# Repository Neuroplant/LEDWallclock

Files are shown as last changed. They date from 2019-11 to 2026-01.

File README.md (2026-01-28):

# LEDWallclock
very low cost Wallclock based on ESP01 and WS2812B Leds 

  # Features:
  - get current time from NTP (instead of buying a RTC-Modul)
  - use free pixels as Color light (MQTT /Clock/colorRGB/set)
  - use Alarm-time (MQTT /Clock/alarm/set)
  - Animation-Alarm (MQTT /Clock/effect/set)

  # MQTT
  you will need an  MQTT Broker (I tested with Mosquitto)
  Topics are:
  - /Uhr/colorRGB/set  &emsp;Use the free frame pixel as Color Light
  - /Uhr/effect/set    &emsp;0..3 will imediatly start Animation
  - /Uhr/timer/set     &emsp;Coutdown in seconds for next Timer/Alarm
  - /Uhr/alarm/set     &emsp;ISO8601 for next Timer/Alarm
  - /Uhr/TimerLimit/set  &emsp;seconds before event the timer is shown
  - /Uhr/Rotation/set  &emsp;pixel to rotate the dial to be upright (I found it to be more convinient in the MQTT section than hardcoded.
  - /Uhr/Csecond/set   &emsp;RGB of the second hand
  - /Uhr/Cminute/set   &emsp;RGB of the minute hand
  - /Uhr/Chour/set     &emsp;RGB if the hour hand
  - /Uhr/Csegment5/set &emsp;RGB of the 5-minutes marks (5, 10, 20, 25, 35, 40, 50, 55)
  - /Uhr/Csegment15/set  &emsp;RGB of the 15-minutes marks (0, 15, 30, 45)
  - /Uhr/Ctimer/set    	&emsp;RGB of the timer shown
  - /Uhr/NextAnimation/set  &emsp;1..3 selects the next Timer/Alarm animaion
  - /Uhr/AniTime/set   &emsp;time the timer/Alarm animation is shown in seconds

# Parts:
 in addition to the WS2812B strip:
   - ESP8266-01 (ESP-01)
   - ESP8266 ESP-01/01S RGB-LED-Controller-Adapter. 
   - 5V Powersupply (or something like this https://www.amazon.de/dp/B0F9Y5LQJB?ref=ppx_yo2ov_dt_b_fed_asin_title)
   
  **when I created this Project it was nessesary to build your own PCB but now you can buy one, that is ready to go (most come with a ESP01 included)
     I will keep everything here in case someone wants to solder it himself**
  - PCB (60mm * 40mm)
  - DC-DC Converter (set to 5V output) (e.g., for 60 LEDs this will be sufficient; for more LEDs, use a bigger one)
    https://www.amazon.de/AZDelivery-LM2596S-Netzteil-Adapter-Arduino/dp/B07DP3JX2X/
  - Level Shifter (e.g., https://www.amazon.de/XCSOURCE®-Logisches-Konverter-Bi-Direktional-TE291/dp/B0148BLZGE/)
  - Resistor 470 Ohm
  - Capacitor 1000µF / 6.3V
  - DC Power Supply**
  # Libraries
  
  - FS / SPIFFS
  - WiFiManager
  - WiFi / WiFiUDP
  - TimeLib (Time)
  - ArduinoJson (v6.x)
  - NeoPixelBus
  - NeoPixelAnimator
  - PubSubClient

|Bibliothek|SPIFFS (File System)|
| --- |:---:|
 | Benötigt für: | Speichern von Konfigurationsdateien und Daten auf dem ESP8266. |
 | Installieren: |Für ESP8266: FS ist standardmäßig enthalten, SPIFFS ebenfalls.|
| |Für ESP32: SPIFFS über Bibliotheksmanager installieren.|

| Bibliothek| WiFiManager|
| --- |:---:|
|Autor: |tzapu|
|Benötigt für: |WLAN-Konfiguration über Captive Portal (falls kein festes WLAN in Code).|
|Arduino IDE Installation:|
|Menü: |Sketch → Bibliothek einbinden → Bibliotheken verwalten → Suche: WiFiManager → Installieren|
|GitHub: |https://github.com/tzapu/WiFiManager|

|Bibliothek: |WiFi (inkl. WiFiUDP)|
| --- |:---:|
|Benötigt für: |WLAN-Verbindung und NTP (UDP) Kommunikation.|
|Hinweis: |Für ESP8266 ist standardmäßig enthalten. 
||Für ESP32: WiFi über Bibliotheksmanager.|

|Bibliothek: |Time (TimeLib)|
| --- |:---:|
|Autor: |Michael Margolis|
|Benötigt für: |Zeitfunktionen wie now(), hour(), minute(), etc.|
|Arduino IDE Installation: |Bibliotheksmanager → Suche: TimeLib → Installieren|
|GitHub: https://github.com/PaulStoffregen/Time|

|Bibliothek: |ArduinoJson|
| --- |:---:|
|Autor: |Benoit Blanchon|
|Benötigt für: |JSON-Parsing für MQTT Konfigurationen.|
|Hinweis: |Version 6.x empfohlen|
|Arduino IDE Installation: |Bibliotheksmanager → Suche: ArduinoJson → Installieren
|GitHub: |https://github.com/bblanchon/ArduinoJson|

|Bibliothek: |NeoPixelBus|
| --- |:---:|
|Autor: |Makuna|
|Benötigt für: |Steuerung der WS2812B LEDs|
|Arduino IDE Installation: |Bibliotheksmanager → Suche: NeoPixelBus → Installieren|
|GitHub: |https://github.com/Makuna/NeoPixelBus|

|Bibliothek: |NeoPixelAnimator|
| --- |:---:|
|Benötigt für: |Animationen / Fade / Blending der LEDs|
|Hinweis: |Wird in der Regel automatisch mit NeoPixelBus mitinstalliert, sonst separat installieren|
|Arduino IDE Installation: |Bibliotheksmanager → Suche: NeoPixelAnimator → Installieren|

|Bibliothek: |PubSubClient|
| --- |:---:|
|Autor: |Nick O'Leary|
|Benötigt für: |MQTT-Kommunikation|
|Arduino IDE Installation: |Bibliotheksmanager → Suche: PubSubClient → Installieren|
|GitHub: |https://github.com/knolleary/pubsubclient|

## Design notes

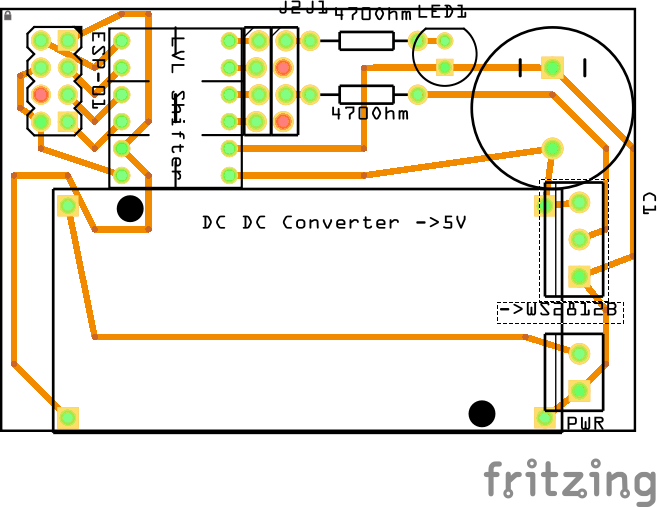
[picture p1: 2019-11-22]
Clock_Leiterplatte-oben.png

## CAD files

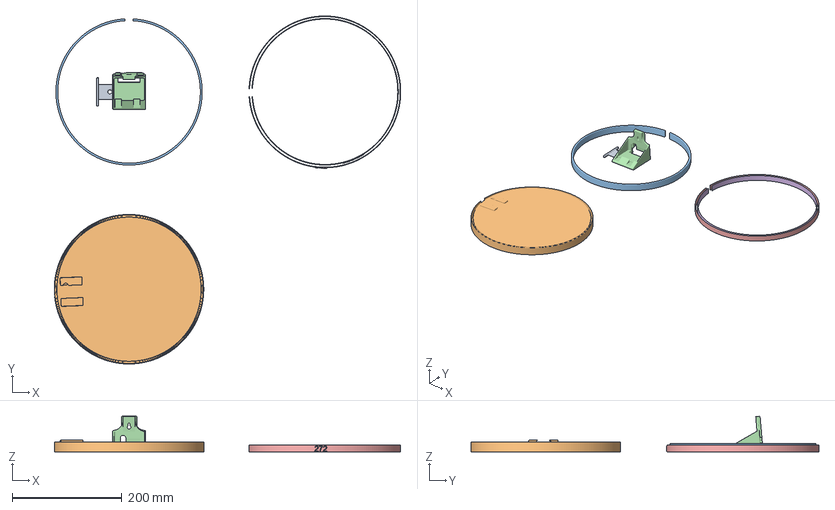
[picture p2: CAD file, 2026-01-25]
ClosedDial2.3mf
632.3 x 635.1 x 65.0 mm
Hanger-Wall
ClosedDial.stl
FixRing.stl
Foot.stl
Testkörper2.stl
Testkörper1.stl

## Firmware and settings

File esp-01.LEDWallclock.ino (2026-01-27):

/*
  LED Wall Clock
  ESP-01 WS2812B with 60 LEDs (or more) on pin 2
  Additional Libraries:
	- FS / SPIFFS
	- WiFiManager
	- WiFi / WiFiUDP
	- TimeLib (Time)
	- ArduinoJson (v6.x)
	- NeoPixelBus
	- NeoPixelAnimator
	- PubSubClient
  
  Features:
  - Get time from NTP (instead of buying an RTC module)
  - Use free pixels as colour light (MQTT /Clock/colorRGB/set)
  - Timer (seconds, max 24h) (MQTT /Clock/timer/set)
  - Animation alarm (MQTT /Clock/effect/set)
  
  Parts:
   - ESP8266-01 (ESP-01)
   - ESP8266 ESP-01/01S RGB-LED-Controller-Adapter. 
   - 5V Powersupply (or something like this https://www.amazon.de/dp/B0F9Y5LQJB?ref=ppx_yo2ov_dt_b_fed_asin_title)
   
   [when I created this Project it was nessesary to build your own PCB but now you can buy one assembled with USB-C Connector
    - PCB (60mm * 40mm)
  - DC-DC Converter (set to 5V output) (e.g., for 60 LEDs this will be sufficient; for more LEDs, use a bigger one)
    https://www.amazon.de/AZDelivery-LM2596S-Netzteil-Adapter-Arduino/dp/B07DP3JX2X/
  - Level Shifter (e.g., https://www.amazon.de/XCSOURCE®-Logisches-Konverter-Bi-Direktional-TE291/dp/B0148BLZGE/)
  - Resistor 470 Ohm
  - Capacitor 1000µF / 6.3V
  - DC Power Supply
  ]
*/

#include <FS.h>               // File system for SPIFFS
#include <WiFiManager.h>      // For WiFi configuration via captive portal
#include <WiFiUdp.h>          // For NTP (UDP)
#include <TimeLib.h>          // Time functions (time_t, now(), etc.)
#include <stdlib.h>           // Standard C++ functions (e.g., map, random)

#ifdef ESP32
  #include <SPIFFS.h>
#endif

#include <ArduinoJson.h>      // https://github.com/bblanchon/ArduinoJson
#include <NeoPixelBus.h>      // https://github.com/Makuna/NeoPixelBus
#include <NeoPixelAnimator.h> // Animations (fade, blend, etc.)

// WiFi Settings

// MQTT Settings
char MQTTServer[40];
char MQTTClient[20];
char MQTTPW[20];

// Flag for saving configuration
bool shouldSaveConfig = false;

// Callback notifying us of the need to save configuration
void saveConfigCallback () {
  Serial.println("Should save config");
  shouldSaveConfig = true;
}

// Hardware Settings
const uint16_t PixelCount = 120;  // Best effect with multiples of 60 LEDs, other numbers also work
const uint8_t PixelPin = 2;       // Ensure this is the correct pin; ignored for ESP8266
int TimerLimit = 1800;            // Timer shows only if remaining time < TimerLimit
int Rotation = 0;                 // If the first pixel is not at "up"

// NTP Settings
IPAddress timeServer(134, 95, 192, 172);  // University of Cologne
const int timeZone = 1;                   // Central European Time
//const int timeZone = -5;  // Eastern Standard Time (USA)
//const int timeZone = -4;  // Eastern Daylight Time (USA)
//const int timeZone = -8;  // Pacific Standard Time (USA)
//const int timeZone = -7;  // Pacific Daylight Time (USA)

// Colour Settings (leave default)
#define colorSaturation 255
NeoPixelBus<NeoGrbFeature, NeoEsp8266Uart1Ws2812xMethod> strip(PixelCount, PixelPin);
RgbColor Csecond(map(255, 0, 255, 0, colorSaturation), map(0, 0, 255, 0, colorSaturation), map(0, 0, 255, 0, colorSaturation));
RgbColor Cminute(map(0, 0, 255, 0, colorSaturation), map(255, 0, 255, 0, colorSaturation), map(0, 0, 255, 0, colorSaturation));
RgbColor Chour(map(0, 0, 255, 0, colorSaturation), map(0, 0, 255, 0, colorSaturation), map(255, 0, 255, 0, colorSaturation));
RgbColor Csegment5(map(10, 0, 255, 0, colorSaturation), map(10, 0, 255, 0, colorSaturation), map(10, 0, 255, 0, colorSaturation));
RgbColor Csegment15(map(20, 0, 255, 0, colorSaturation), map(20, 0, 255, 0, colorSaturation), map(20, 0, 255, 0, colorSaturation));
RgbColor Ctimer(map(100, 0, 255, 0, colorSaturation), map(0, 0, 255, 0, colorSaturation), map(0, 0, 255, 0, colorSaturation));
RgbColor black(0);

// Animation Settings (leave default)
int AniTime = 10;       // How long the animation is shown (seconds)
int NextAnimation = 1;  // Animation selected for alarm

// Input RGB from MQTT
long FrameRed = 50;    // 0..255
long FrameGreen = 50;  // 0..255
long FrameBlue = 50;   // 0..255

// Alarm
time_t EndTime = now();      // Alarm triggers at EndTime
unsigned long RestTime = 0;  // Seconds remaining until alarm

// Time when the digital clock was last displayed
time_t prevDisplay = 0;

// WiFi radio status
int status = WL_IDLE_STATUS;

// UDP instance for sending/receiving packets
WiFiUDP Udp;
unsigned int localPort = 8888;  // Local port for UDP
WiFiClient net;                  // NTP client

// Rotate by [Rotation] pixels to maintain clock orientation
int Protate(int i) {
  i = i + Rotation;
  if (i >= PixelCount) {
    i = i - PixelCount;
  }
  return i;
}

// Timer storage
constexpr size_t maxTimerStored = 16;
time_t TimerList[maxTimerStored] {0};

// Store new timer in the list
bool StoreTimer(time_t value) {
  const time_t current = now();

  // Remove expired timers
  for (int i = 0; i < maxTimerStored; i++) {
    if (TimerList[i] <= current) {
      TimerList[i] = 0;
    }
  }

  // Add new timer
  for (int i = 0; i < maxTimerStored; i++) {
    if (TimerList[i] == 0) {
      TimerList[i] = value;
      return true;
    }
  }

  return false; // No free slot
}

// Get next timer from the list
time_t QueryTimer() {
  time_t value = LONG_MAX;
  for (int i = 0; i < maxTimerStored; i++) {
    if ((TimerList[i] != 0) && (TimerList[i] < value)) {
      value = TimerList[i];
    }
  }
  return value;
}

// MQTT client
PubSubClient client(net);
void AnimationSelect(int value);

// Connect to MQTT and subscribe
void connect() {
  while (WiFi.status() != WL_CONNECTED) delay(1000);
  while (!client.connect(MQTTServer, MQTTClient, MQTTPW)) delay(1000);

  // Subscribe to relevant topics
  client.subscribe("/Uhr/colorRGB/set");
  client.subscribe("/Uhr/effect/set");
  client.subscribe("/Uhr/timer/set");
  client.subscribe("/Uhr/alarm/set");
  client.subscribe("/Uhr/TimerLimit/set");
  client.subscribe("/Uhr/Rotation/set");
  client.subscribe("/Uhr/Csecond/set");
  client.subscribe("/Uhr/Cminute/set");
  client.subscribe("/Uhr/Chour/set");
  client.subscribe("/Uhr/Csegment5/set");
  client.subscribe("/Uhr/Csegment15/set");
  client.subscribe("/Uhr/Ctimer/set");
  client.subscribe("/Uhr/NextAnimation/set");
  client.subscribe("/Uhr/AniTime/set");
}

// MQTT callback handler
void callback(char* topic, byte* payload, unsigned int length) {
  //String topicStr = topic; 
  payload[length] = 0;
  String Payload = String(( char *) payload);

  // Change colour
  if (strcmp(topic, "/Uhr/colorRGB/set") == 0) {
    FrameRed = Payload.substring(0, Payload.indexOf(',')).toInt();
    FrameGreen = Payload.substring(Payload.indexOf(',') + 1, Payload.lastIndexOf(',')).toInt();
    FrameBlue = Payload.substring(Payload.lastIndexOf(',') + 1).toInt();
  }

  // Start animation
  if (strcmp(topic, "/Uhr/effect/set") == 0) {
    int i = Payload.substring(0, length).toInt();
    AnimationSelect(i);
  }

  // Start timer
  if (strcmp(topic, "/Uhr/timer/set") == 0) {
    int i = Payload.substring(0, length).toInt();
    StoreTimer(i + now());
  }

  // Set alarm
  if (strcmp(topic, "/Uhr/alarm/set") == 0) {
    if (Payload != "UNDEF") {
      tm timetm;
      if (Payload.substring(10, 11)=="T") {
        strptime(Payload.c_str(), "%Y-%m-%dT%H:%M:%S", &timetm);
      } else {
        strptime(Payload.c_str(), "%Y-%m-%d %H:%M:%S", &timetm);
      }
      StoreTimer(mktime(&timetm));
    }
  }

  // Set timer limit
  if (strcmp(topic, "/Uhr/TimerLimit/set") == 0) {
    int i = Payload.substring(0, length).toInt();
    TimerLimit = i;
    char restate[length];
    String(TimerLimit).toCharArray(restate, length);
    client.publish("/Uhr/TimerLimit/", restate);
  }

  // Set rotation
  if (strcmp(topic, "/Uhr/Rotation/set") == 0) {
    int i = Payload.substring(0, length).toInt();
    Rotation = i;
    char restate[length];
    String(Rotation).toCharArray(restate, length);
    client.publish("/Uhr/Rotation/", restate);
  }

  // Set second hand colour
  if (strcmp(topic, "/Uhr/Csecond/set") == 0) {
    long TRed = Payload.substring(0, Payload.indexOf(',')).toInt();
    long TGreen = Payload.substring(Payload.indexOf(',') + 1, Payload.lastIndexOf(',')).toInt();
    long TBlue = Payload.substring(Payload.lastIndexOf(',') + 1).toInt();
    Csecond = RgbColor(map(TRed, 0, 255, 0, colorSaturation),
                        map(TGreen, 0, 255, 0, colorSaturation),
                        map(TBlue, 0, 255, 0, colorSaturation));
    char restate[length];
    String i = String(TRed) + "," + String(TGreen) + "," + String(TBlue);
    i.toCharArray(restate, length);
    client.publish("/Uhr/Csecond/", restate);
  }

 //"/Uhr/Cminute/set");
  if (strcmp(topic, "/Uhr/Cminute/set") == 0) {
    long TRed = Payload.substring(0, Payload.indexOf(',')).toInt();
    long TGreen = Payload.substring(Payload.indexOf(',') + 1, Payload.lastIndexOf(',')).toInt();
    long TBlue = Payload.substring(Payload.lastIndexOf(',') + 1).toInt();
    Cminute = RgbColor(map(TRed, 0, 255, 0, colorSaturation), map(TGreen, 0, 255, 0, colorSaturation), map(TBlue, 0, 255, 0, colorSaturation));
    char restate[length];
    String i = (String(TRed) + "," + String(TGreen) + "," + String(TBlue));
    i.toCharArray(restate, length);
    client.publish("/Uhr/Cminute/", restate);
  }
  //"/Uhr/Chour/set");
  if (strcmp(topic, "/Uhr/Chour/set") == 0) {
    long TRed = Payload.substring(0, Payload.indexOf(',')).toInt();
    long TGreen = Payload.substring(Payload.indexOf(',') + 1, Payload.lastIndexOf(',')).toInt();
    long TBlue = Payload.substring(Payload.lastIndexOf(',') + 1).toInt();
    Chour = RgbColor(map(TRed, 0, 255, 0, colorSaturation), map(TGreen, 0, 255, 0, colorSaturation), map(TBlue, 0, 255, 0, colorSaturation));
    char restate[length];
    String i = (String(TRed) + "," + String(TGreen) + "," + String(TBlue));
    i.toCharArray(restate, length);
    client.publish("/Uhr/Chour/", restate);
  }
  //"/Uhr/Csegment5/set");
  if (strcmp(topic, "/Uhr/Csegment5/set") == 0) {
    long TRed = Payload.substring(0, Payload.indexOf(',')).toInt();
    long TGreen = Payload.substring(Payload.indexOf(',') + 1, Payload.lastIndexOf(',')).toInt();
    long TBlue = Payload.substring(Payload.lastIndexOf(',') + 1).toInt();
    Csegment5 = RgbColor(map(TRed, 0, 255, 0, colorSaturation), map(TGreen, 0, 255, 0, colorSaturation), map(TBlue, 0, 255, 0, colorSaturation));
    char restate[length];
    String i = (String(TRed) + "," + String(TGreen) + "," + String(TBlue));
    i.toCharArray(restate, length);
    client.publish("/Uhr/Csegment5/", restate);
  }
  //"/Uhr/Csegment15/set");
  if (strcmp(topic, "/Uhr/Csegment15/set") == 0) {
    long TRed = Payload.substring(0, Payload.indexOf(',')).toInt();
    long TGreen = Payload.substring(Payload.indexOf(',') + 1, Payload.lastIndexOf(',')).toInt();
    long TBlue = Payload.substring(Payload.lastIndexOf(',') + 1).toInt();
    Csegment15 = RgbColor(map(TRed, 0, 255, 0, colorSaturation), map(TGreen, 0, 255, 0, colorSaturation), map(TBlue, 0, 255, 0, colorSaturation));
    char restate[length];
    String i = (String(TRed) + "," + String(TGreen) + "," + String(TBlue));
    i.toCharArray(restate, length);
    client.publish("/Uhr/Csegment15/", restate);
  }
  //"/Uhr/Ctimer/set");
  if (strcmp(topic, "/Uhr/Ctimer/set") == 0) {
    long TRed = Payload.substring(0, Payload.indexOf(',')).toInt();
    long TGreen = Payload.substring(Payload.indexOf(',') + 1, Payload.lastIndexOf(',')).toInt();
    long TBlue = Payload.substring(Payload.lastIndexOf(',') + 1).toInt();
    Ctimer = RgbColor(map(TRed, 0, 255, 0, colorSaturation), map(TGreen, 0, 255, 0, colorSaturation), map(TBlue, 0, 255, 0, colorSaturation));
    char restate[length];
    String i = (String(TRed) + "," + String(TGreen) + "," + String(TBlue));
    i.toCharArray(restate, length);
    client.publish("/Uhr/Ctimer/", restate);
  }
  //"/Uhr/NextAnimation/set");
  if (strcmp(topic, "/Uhr/NextAnimation/set") == 0) {
    int i = Payload.substring(0, length).toInt();
    NextAnimation = i;
    char restate[length];
    String(NextAnimation).toCharArray(restate, length);
    client.publish("/Uhr/NextAnimation/", restate);
  }
  //"/Uhr/AniTime/set");
  if (strcmp(topic, "/Uhr/AniTime/set") == 0) {
    int i = Payload.substring(0, length).toInt();
    AniTime = i;
    char restate[length];
    String(AniTime).toCharArray(restate, length+1);
    client.publish("/Uhr/AniTime/", restate);
  }
}

///Animation
//taken from the examples at NeoPixelBus

//Animaton 1 (NeoPixelFunLoop)
const uint16_t AnimCount = PixelCount / 5 * 2 + 1;  // we only need enough animations for the tail and one extra
const uint16_t PixelFadeDuration = 300;             // third of a second
// one second divide by the number of pixels = loop once a second
const uint16_t NextPixelMoveDuration = 1000 / PixelCount;  // how fast we move through the pixels
NeoGamma<NeoGammaTableMethod> colorGamma;                  // for any fade animations, best to correct gamma

struct MyAnimationState {
  RgbColor StartingColor;
  RgbColor EndingColor;
  uint16_t IndexPixel;  // which pixel this animation is effecting
};
NeoPixelAnimator animations(AnimCount);  // NeoPixel animation management object
MyAnimationState animationState[AnimCount];
uint16_t frontPixel = 0;  // the front of the loop
RgbColor frontColor;      // the color at the front of the loop

void SetRandomSeed(void) {
  uint32_t seed;
  // random works best with a seed that can use 31 bits
  // analogRead on a unconnected pin tends toward less than four bits
  seed = analogRead(0);
  delay(1);
  for (int shifts = 3; shifts < 31; shifts += 3) {
    seed ^= analogRead(0) << shifts;
    delay(1);
  }
  randomSeed(seed);
}
void FadeOutAnimUpdate(const AnimationParam& param) {
  // this gets called for each animation on every time step
  // progress will start at 0.0 and end at 1.0
  // we use the blend function on the RgbColor to mix
  // color based on the progress given to us in the animation
  RgbColor updatedColor = RgbColor::LinearBlend(
    animationState[param.index].StartingColor,
    animationState[param.index].EndingColor,
    param.progress);
  // apply the color to the strip
  strip.SetPixelColor(animationState[param.index].IndexPixel,
                      colorGamma.Correct(updatedColor));
}
void LoopAnimUpdate(const AnimationParam& param) {
  // wait for this animation to complete,
  // we are using it as a timer of sorts
  if (param.state == AnimationState_Completed) {
    // done, time to restart this position tracking animation/timer
    animations.RestartAnimation(param.index);
    // pick the next pixel inline to start animating
    //
    frontPixel = (frontPixel + 1) % PixelCount;  // increment and wrap
    if (frontPixel == 0) {
      // we looped, lets pick a new front color
      frontColor = HslColor(random(360) / 360.0f, 1.0f, 0.25f);
    }
    uint16_t indexAnim;
    // do we have an animation available to use to animate the next front pixel?
    // if you see skipping, then either you are going to fast or need to increase
    // the number of animation channels
    if (animations.NextAvailableAnimation(&indexAnim, 1)) {
      animationState[indexAnim].StartingColor = frontColor;
      animationState[indexAnim].EndingColor = RgbColor(0, 0, 0);
      animationState[indexAnim].IndexPixel = frontPixel;
      animations.StartAnimation(indexAnim, PixelFadeDuration, FadeOutAnimUpdate);
    }
  }
}

///Animation 2 (FunRandomChange)
NeoPixelAnimator animations02(PixelCount);  // NeoPixel animation management object

struct MyAnimationState2 {
  RgbColor StartingColor;
  RgbColor EndingColor;
};
MyAnimationState2 animationState02[PixelCount];

void BlendAnimUpdate02(const AnimationParam& param) {
  // this gets called for each animation on every time step
  // progress will start at 0.0 and end at 1.0
  // we use the blend function on the RgbColor to mix
  // color based on the progress given to us in the animation
  RgbColor updatedColor = RgbColor::LinearBlend(
    animationState02[param.index].StartingColor,
    animationState02[param.index].EndingColor,
    param.progress);
  // apply the color to the strip
  strip.SetPixelColor(param.index, updatedColor);
}
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
void loop() {

  client.loop();
  if (!client.connected()) {
    connect();
  }
  if (now() != prevDisplay) {  //update the display only if time has changed
    prevDisplay = now();
    digitalClockDisplay();
  }
}

void ClockFrame(int Red, int Green, int Blue) {
  RgbColor Cfill(Red, Green, Blue);
  //delete hands and write all leds in selected color
  strip.ClearTo(Cfill);
  //publish to mqtt as feedback
  char restate[12];
  String i = (String(Red) + "," + String(Green) + "," + String(Blue));
  i.toCharArray(restate, 12);
  client.publish("/Uhr/colorRGB", restate);
}

int ClockSegments(RgbColor Cvalue5, RgbColor Cvalue15) {
  //show 5-minute segments
  for (int i = 0; i <= 11; i++) {
    strip.SetPixelColor(Protate(i * (PixelCount / 60) * 5), Cvalue5);
    strip.SetPixelColor(Protate(1 + (i * (PixelCount / 60) * 5)), Cvalue5);
  }
  //show 15-minute segments
  for (int i = 0; i <= 3; i++) {
    strip.SetPixelColor(Protate(i * (PixelCount / 60) * 15), Cvalue15);
    strip.SetPixelColor(Protate(1 + (i * (PixelCount / 60) * 15)), Cvalue15);
  }
  return 1;
}

void ClockHands(RgbColor CvalueH, RgbColor CvalueM, RgbColor CvalueS) {
  //show hour hand
  int i = (hourFormat12() * 5) + (int)(minute() / 12 + 0.5);
  if (i > 59) i -= 60;
  strip.SetPixelColor(Protate(map(i, 0, 59, 0, PixelCount - 1)), CvalueH);
  //show minute hand
  strip.SetPixelColor(Protate(map(minute(), 0, 59, 0, PixelCount - 1)), CvalueM);
  //show second hand
  strip.SetPixelColor(Protate(map(second(), 0, 59, 0, PixelCount - 1)), CvalueS);
}

void ClockTimer(time_t value, RgbColor Cvalue) {
  if (value < now()) {
    RestTime = 0;
  } else {
    RestTime = (unsigned long)value - (unsigned long)now();
  }
  if (RestTime > 0) {
    char restate[24];
    sprintf(restate, "%d", RestTime);
    client.publish("/Uhr/timer", restate, false);
    sprintf(restate, "%04d-%02d-%02d %02d:%02d:%02d", year(value), month(value), day(value), hour(value), minute(value), second(value));
    client.publish("/Uhr/alarm", restate, false);
    if ((RestTime >= 3600) && (RestTime <= TimerLimit)) {
      // >1 hour
      for (int i = 0; i < map(RestTime, 0, 24 * 3600, 0, PixelCount); i++) {
        strip.SetPixelColor(Protate(PixelCount - i), Cvalue);
      }
    }

    if ((RestTime > 60) && (RestTime < 3600) && (RestTime <= TimerLimit)) {
      // >1 Minute
      for (int i = 0; i <= map(RestTime, 0, 3600, 0, PixelCount); i++) {
        strip.SetPixelColor(Protate(i), Ctimer);
      }
    }

    if ((RestTime <= 60) && (RestTime <= TimerLimit)) {
      //< 1 Minute
      for (int i = 0; i <= map(RestTime, 0, 60, 0, PixelCount); i++) {
        strip.SetPixelColor(Protate(i), Ctimer); 
      }
    }

    if (RestTime <= 1) {
      AnimationSelect(NextAnimation);
		NextAnimation++;
		if (NextAnimation > 3) Nextanimation = 1;
      }
  }
}

void digitalClockDisplay() {
  Serial.println("digitalClockDisplay");



  //Clock Frame alias Light
  ClockFrame(FrameRed, FrameGreen, FrameBlue);
   //Timer
  ClockTimer(QueryTimer(), Ctimer);
//Static markers for 5/15 Minutes
  ClockSegments(Csegment5, Csegment15);
//Clock Hands
   ClockHands(Chour, Cminute, Csecond);
  
  strip.Show();
}
/*-------- NTP code ----------*/
const int NTP_PACKET_SIZE = 48;      // NTP time is in the first 48 bytes of message
byte packetBuffer[NTP_PACKET_SIZE];  //buffer to hold incoming & outgoing packets
time_t getNtpTime() {
  while (Udp.parsePacket() > 0)
    ;  // discard any previously received packets
  sendNTPpacket(timeServer);
  uint32_t beginWait = millis();
  while (millis() - beginWait < 1500) {
    int size = Udp.parsePacket();
    if (size >= NTP_PACKET_SIZE) {
      Udp.read(packetBuffer, NTP_PACKET_SIZE);  // read packet into the buffer
      unsigned long secsSince1900;
      // convert four bytes starting at location 40 to a long integer
      secsSince1900 = (unsigned long)packetBuffer[40] << 24;
      secsSince1900 |= (unsigned long)packetBuffer[41] << 16;
      secsSince1900 |= (unsigned long)packetBuffer[42] << 8;
      secsSince1900 |= (unsigned long)packetBuffer[43];
      return secsSince1900 - 2208988800UL + timeZone * SECS_PER_HOUR;
    }
  }
  return 0;  // return 0 if unable to get the time
}
// send an NTP request to the time server at the given address
void sendNTPpacket(IPAddress& address) {
  // set all bytes in the buffer to 0
  memset(packetBuffer, 0, NTP_PACKET_SIZE);
  // Initialize values needed to form NTP request
  // (see URL above for details on the packets)
  packetBuffer[0] = 0b11100011;  // LI, Version, Mode
  packetBuffer[1] = 0;           // Stratum, or type of clock
  packetBuffer[2] = 6;           // Polling Interval
  packetBuffer[3] = 0xEC;        // Peer Clock Precision
  // 8 bytes of zero for Root Delay & Root Dispersion
  packetBuffer[12] = 49;
  packetBuffer[13] = 0x4E;
  packetBuffer[14] = 49;
  packetBuffer[15] = 52;
  // all NTP fields have been given values, now
  // you can send a packet requesting a timestamp:
  Udp.beginPacket(address, 123);  //NTP requests are to port 123
  Udp.write(packetBuffer, NTP_PACKET_SIZE);
  Udp.endPacket();
}
/*-------- NTP code ----------*/														 

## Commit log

2019-12-02 corrected hour hand calculation
    [esp-01.LEDWallclock.ino]
2020-07-30 completed parts section
    forgot the LEDS 👍
2026-01-25 Update esp-01.LEDWallclock.ino
    After 7 years some major changes and improvements.
2026-01-25 Example for a Dial
    [ClosedDial2.3mf]
2026-01-26 Update esp-01.LEDWallclock.ino
    cleanup
2026-01-26 Delete LEDWallclock.rule
    Better Gone than wrong
2026-01-27 Update esp-01.LEDWallclock.ino
    byte* to string?
